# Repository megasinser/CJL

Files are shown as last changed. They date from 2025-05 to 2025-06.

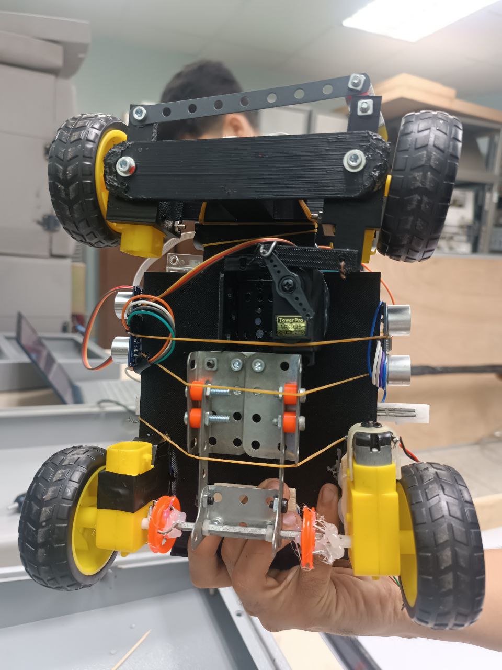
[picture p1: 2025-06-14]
v-photos/BOTTOM.jpg

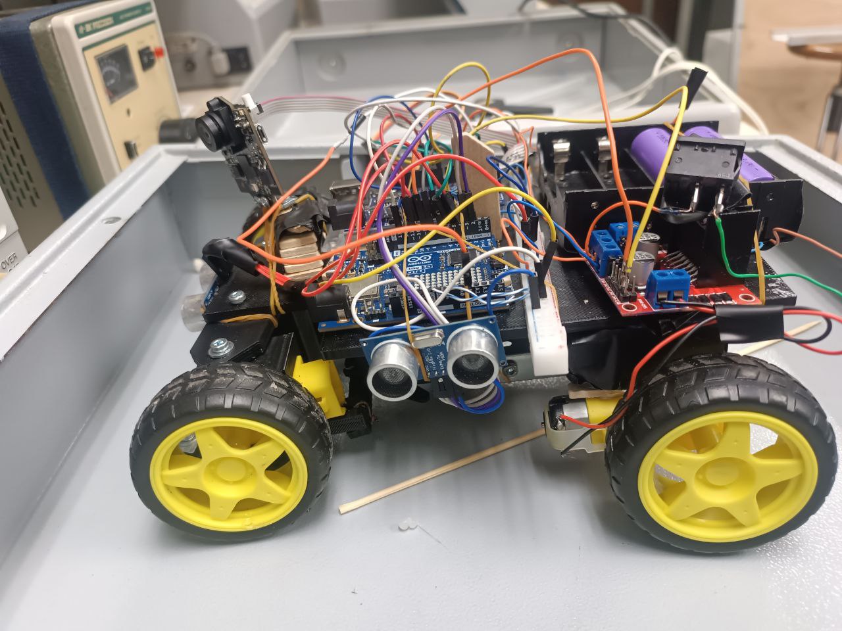
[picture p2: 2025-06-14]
v-photos/LEFT.jpg

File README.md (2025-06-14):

Hi, we are the CJL team, and this is our GitHub repository, where we will be explaining and providing all the relevant information regarding the development of our autonomous car for the WRO Future Engineers category.

Engineering materials
This repository contains engineering materials of a self-driven vehicle's model participating in the WRO Future Engineers competition in the season 2025.

Arduino UNO R3

Arduino UNO R4

Servomotor MG995

Ultrasonic sensor (3)

9v battery

Pixy CAM 2.1 with comunication cable

wheels (4)

Hobby Gearmotor - 140 RPM (2)

H bridge

mini proto board 

jumpers and UTP wires 

4 18650 battteries

## Content

* `t-photos` contains 2 photos of the team (an official one and one funny photo with all team members)

* `v-photos` contains 6 photos of the vehicle (from every side, from top and bottom)
* `video` contains the video.md file with the link to a video where driving demonstration exists
* `schemes` 

* In the picture you can watch how the components that make the car works are conected, without even considering the color detection system.

* `src` contains code of control software for all components which were programmed to participate in the competition

* `other`   

## Introduction and Project description

For the creation of our autonomous car, I utilized several key components: two Arduino boards, three ultrasonic sensors, an H-bridge, four 18650 batteries, a 3D printed chassis, a reduction motor, and three motor enclosures (one with a motor, two with reduction gears but without motors).

To start, I assembled the chassis, as shown in the photo, and proceeded to connect the two Arduino boards. The three ultrasonic sensors were strategically placed: one on the right side, one on the left, and one in the front. I defined the appropriate pins for each sensor to gather distance data, allowing the robot to detect obstacles and avoid collisions. This data was then used to implement the turning logic, helping the car navigate the track and avoid obstacles.

I also connected a reduction motor to another motor reduction housing via a gearbox, as required by the competition rules. The H-bridge was used to control the motor's direction, allowing it to move forward or backward depending on the signal received from the control system.

For color detection, I integrated the Pixy camera with an Arduino using the PixyMon software. The camera was programmed to detect red, green, orange, and blue colors. Red and green were used to identify blocks or obstacles on the track, while blue and orange  were designated for detecting the track's lines at each corner. The camera’s output was processed by an Arduino, and based on the detected color, the Arduino would send a signal to the second Arduino to control the car's movement. For instance, if the camera detected green, the car would turn left, and if green was detected, it would turn left.

Additionally, the Pixy camera sends information about the color detected (including the X and Y coordinates of the block) to the Arduino, which then sends a HIGH signal to specific pins. This signal is received by the second Arduino to trigger the appropriate response: turning left for red or right for green.

To track the car’s laps, I implemented a counter in the Arduino connected to the Pixy camera. Each time the camera detected a set of four orange lines, one at each corner of the track, it counted as a full lap. After three laps, the Arduino would send a stop signal to the motor Arduino to halt the motors.

The entire system was powered by a total of 8 volts from four 18650 batteries, with a 5-volt regulator used to supply power to the Arduino boards, sensors, and servos.

## About us

Meet Our Team:

We are a team made up of Luis, Carlos, and José, and we share a strong passion for robotics. Each one of us brings something unique to the table, and together, we work hard to create something truly amazing.

Carlos: Carlos is in charge of the mechanical and physical side of the vehicle. He’s the one who builds everything and makes sure the robot’s structure is solid and works well. His skills in mechanics are what make our robot functional and reliable.

José: José is the one who handles the programming and logic. He loves coding and is great at solving problems. His work ensures the robot works the way it’s supposed to and can make decisions on its own.

Luis: Luis is also focused on programming, but he’s especially good at connecting everything together and solving technical issues. His ability to troubleshoot and fix problems helps keep everything running smoothly.

Our Approach:

As a team, we’re all about working together and learning from each other. Carlos handles the physical build, José writes the code, and Luis makes sure everything fits together and works perfectly. We each have our strengths, and by combining them, we’re able to push the limits of what we can create in robotics. We’re excited to see where our skills and teamwork take us!

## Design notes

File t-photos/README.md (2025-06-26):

Team's photos
Team picture
funny picture

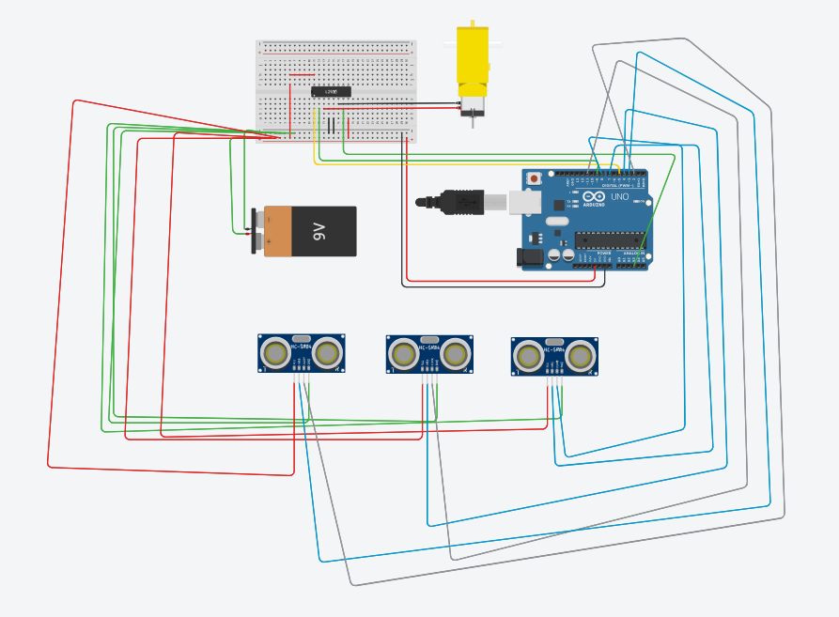
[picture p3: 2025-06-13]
schemes/image.png

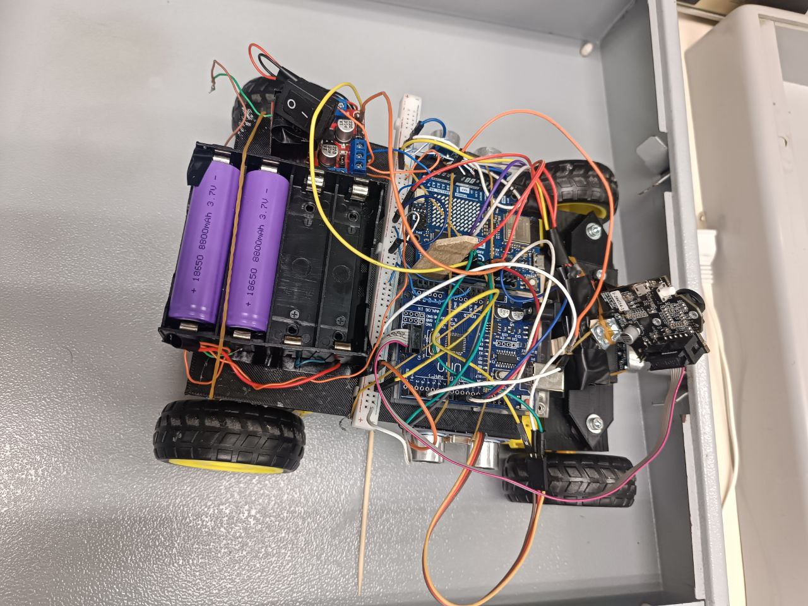
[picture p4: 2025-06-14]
v-photos/TOP.jpg

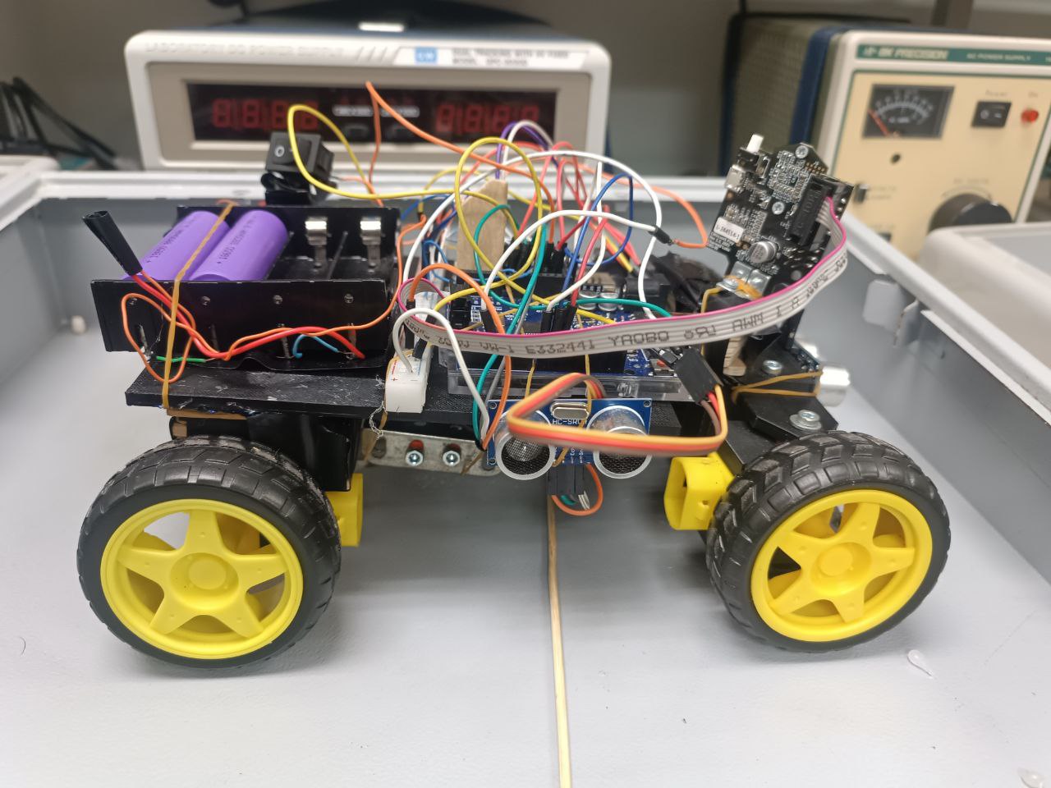
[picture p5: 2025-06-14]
v-photos/RIGHT.jpg

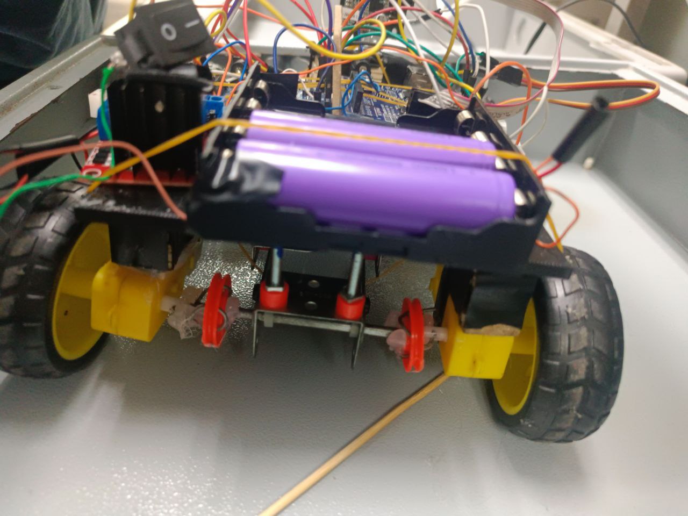
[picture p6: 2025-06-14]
v-photos/BACK.jpg

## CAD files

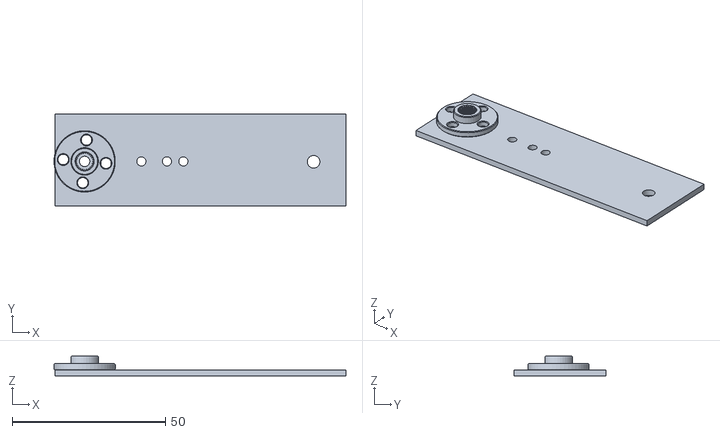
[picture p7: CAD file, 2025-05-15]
models/Direccion_parte_1.stl
95.3 x 30.0 x 6.50

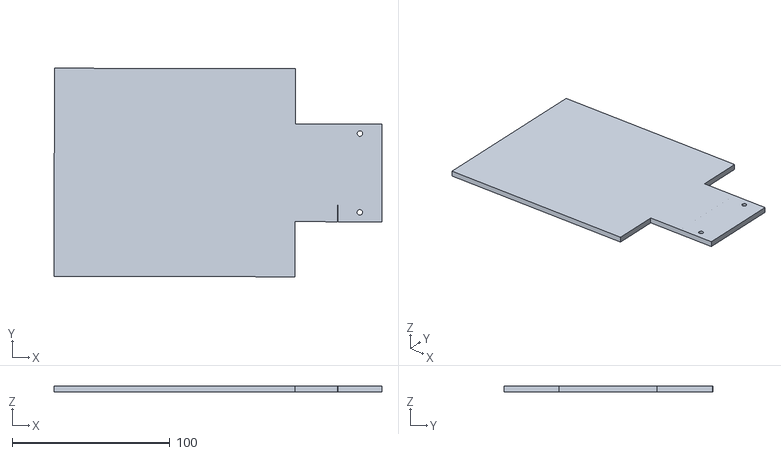
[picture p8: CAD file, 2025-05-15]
models/Chasis.stl
208.1 x 132.4 x 4.00

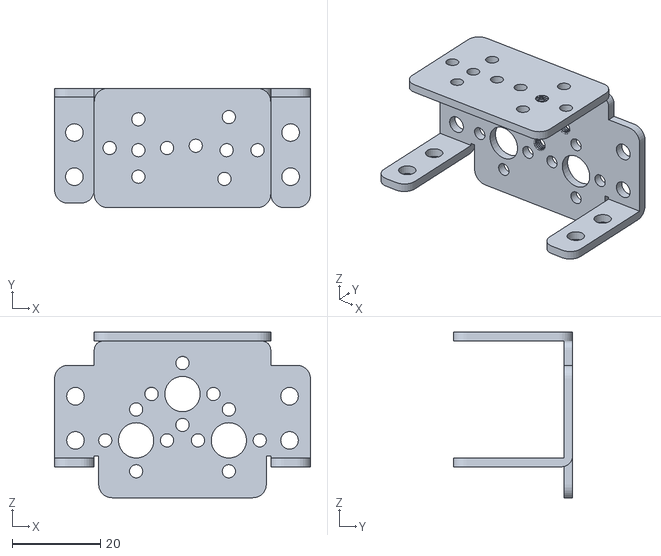
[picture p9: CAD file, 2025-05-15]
models/Soporte_Servo.stl
58.0 x 27.0 x 37.5

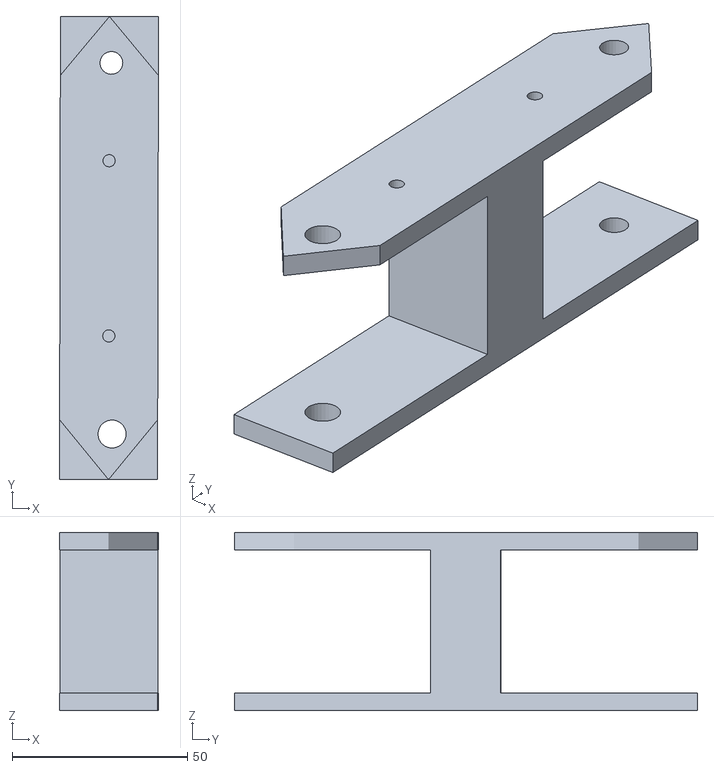
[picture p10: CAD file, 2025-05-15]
models/Soporte_Direccion.stl
28.3 x 132.2 x 50.8

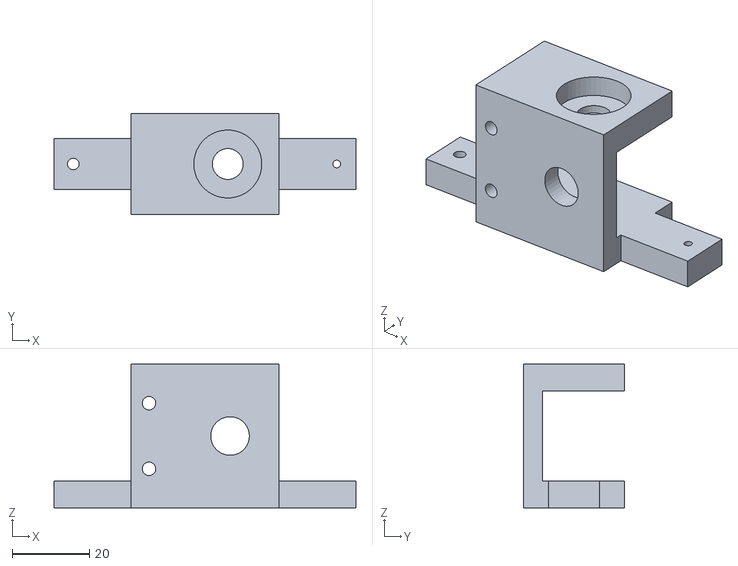
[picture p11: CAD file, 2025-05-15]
models/Abrazadera_A.stl
78.2 x 26.2 x 37.2

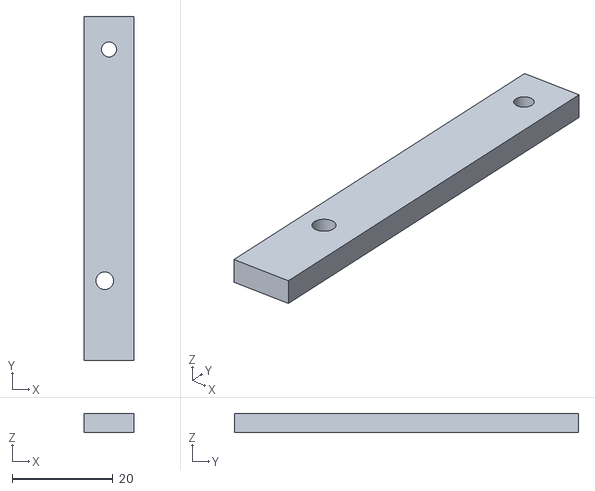
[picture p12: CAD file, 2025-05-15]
models/Direccion_parte_2.stl
10.0 x 68.4 x 3.80

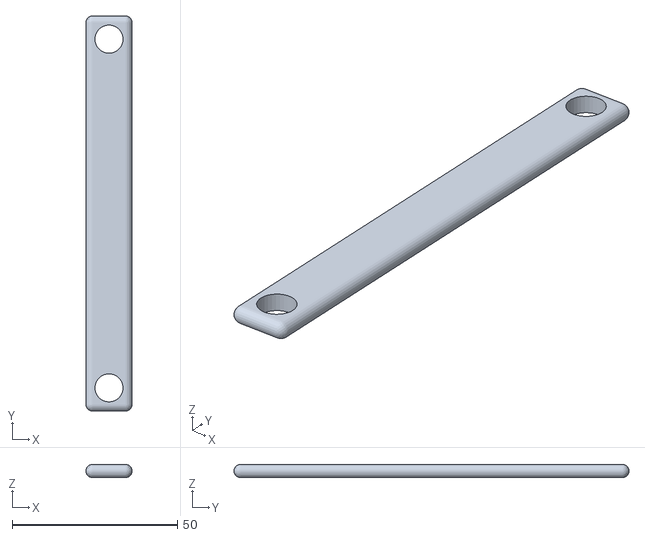
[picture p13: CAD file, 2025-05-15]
models/Barra_Direccion.stl
14.0 x 119.5 x 4.00

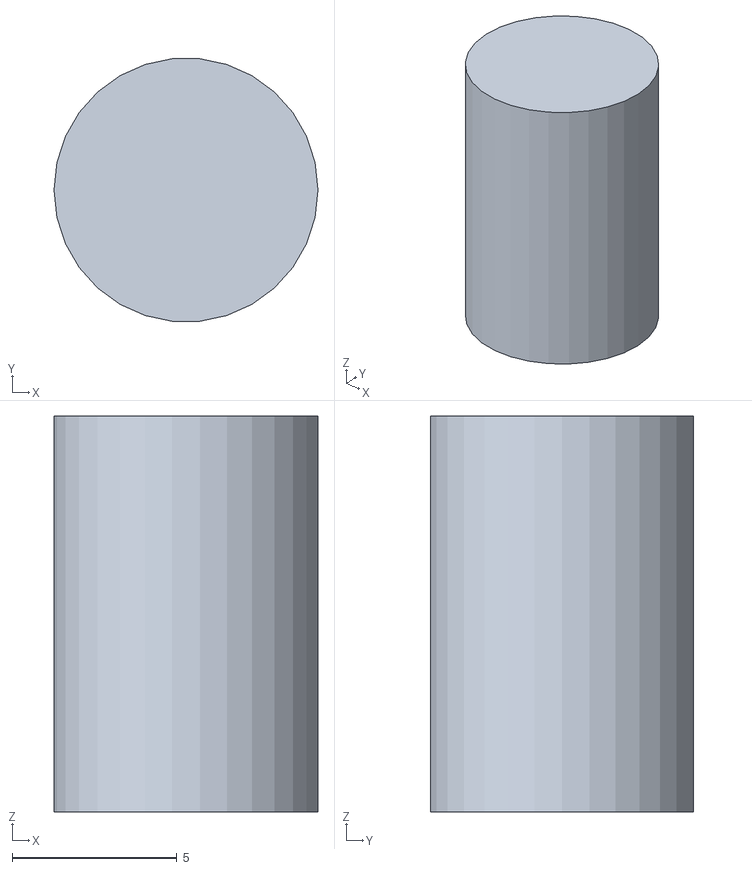
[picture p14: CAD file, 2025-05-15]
models/PosteABCD.stl
8.00 x 7.96 x 12.0

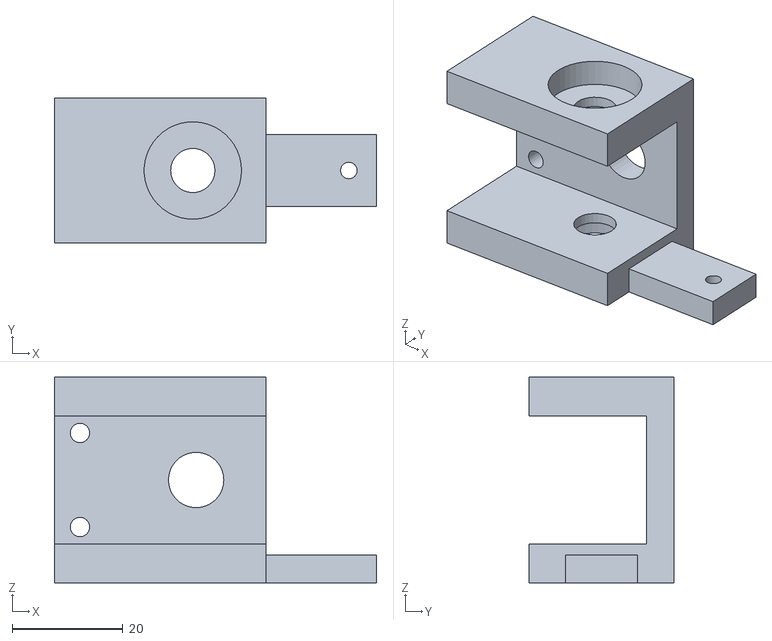
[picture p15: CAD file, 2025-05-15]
models/Abrazadera_B.stl
58.2 x 26.2 x 37.2

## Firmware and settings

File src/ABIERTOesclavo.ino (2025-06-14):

#include <Servo.h>
#include <NewPing.h>

// Definir pines
const int pinServo = 6;
const int pinMotorAdelante = 9;  // Pin PWM para el motor de avance
const int pinMotorAtras = A0;    // Pin PWM para el motor de retroceso (sin uso en este código)
const int pinEnable = 5;         // Pin para habilitar el puente H (Enable) para controlar la velocidad
const int pinAvviso = A1;        // Pin donde se recibe la señal de vuelta completada (A0)

// Definir ángulos del servo
const int ANGULO_CENTRO = 80;
const int ANGULO_IZQUIERDA = 160;
const int ANGULO_DERECHA = 20;
const int ANGULO_IZQUIERDA_C = 120;
const int ANGULO_DERECHA_C = 60;

// Configuración de los sensores ultrasónicos
const int PIN_TRIGGER_1 = 7;
const int PIN_ECHO_1 = 8;
const int MAX_DISTANCIA_1 = 150;  // Distancia máxima de detección en cm para el primer sensor (izquierda)
NewPing sonar1(PIN_TRIGGER_1, PIN_ECHO_1, MAX_DISTANCIA_1);

const int PIN_TRIGGER_2 = 3;
const int PIN_ECHO_2 = 2;
const int MAX_DISTANCIA_2 = 150;  // Distancia máxima de detección en cm para el segundo sensor (derecha)
NewPing sonar2(PIN_TRIGGER_2, PIN_ECHO_2, MAX_DISTANCIA_2);

const int PIN_TRIGGER_3 = 4;
const int PIN_ECHO_3 = 11;
const int MAX_DISTANCIA_3 = 200;  // Distancia máxima de detección en cm para el sensor de frente
NewPing sonar3(PIN_TRIGGER_3, PIN_ECHO_3, MAX_DISTANCIA_3);

// Rango de distancia de referencia (margen tolerable)
const int DISTANCIA_MIN = 20;  // Distancia mínima aceptable (en cm)
const int DISTANCIA_MAX = 30;  // Distancia máxima aceptable (en cm)

// Velocidad fija para los motores (controlada por el pin enable)
const int VELOCIDAD = 250;  // Ajusta la velocidad aquí (valor entre 0 y 255)

Servo miServo;  // Crear objeto servo

bool detenerRobot = false;  // Variable para determinar si detener el robot

void setup() {
  pinMode(13, INPUT);  // Pin 13 como entrada (rojo)
  pinMode(12, INPUT);  // Pin 12 como entrada (verde)
  pinMode(10, INPUT);  // Pin 10 como entrada (ninguno)
  pinMode(pinAvviso, INPUT);  // Configurar A0 (pinAvviso) como entrada
  
  // Inicializar el servo
  miServo.attach(pinServo);
  
  // Configuración de los pines de los motores
  pinMode(pinMotorAdelante, OUTPUT);
  pinMode(pinMotorAtras, OUTPUT);  // No se utiliza en este código
  pinMode(pinEnable, OUTPUT);  // Configurar el pin Enable como salida
  
  // Inicialización del servo en el centro
  miServo.write(ANGULO_CENTRO);

  // Configuración de la comunicación serial para monitorear la distancia
  Serial.begin(9600);
  Serial.println("Esclavo listo para recibir datos...");
}

void loop() {
  // Comprobar si se recibe la señal del primer Arduino para detener el robot
  int estadoAvviso = digitalRead(pinAvviso);  // Leer el pin A1
  
  if (estadoAvviso == HIGH) {
    Serial.println("Vueltas completadas. Deteniendo el robot...");
    detenerRobot = true;  // Cambiar el estado para detener el robot
  }

  if (detenerRobot) {
    // Si la variable detenerRobot es true, se detiene todo el funcionamiento del robot
    digitalWrite(pinMotorAdelante, LOW);  // Detener motor
    Serial.println("Robot detenido permanentemente.");
    return;  // Detener el ciclo del loop
  }

  int estadoRojo = digitalRead(13);  // Leer pin 13 (rojo)
  int estadoVerde = digitalRead(12);  // Leer pin 12 (verde)
  int estadoNinguno = digitalRead(10);  // Leer pin 10 (ninguno)

  // Imprimir el color detectado basado en el pin activo
  if (estadoRojo == HIGH) {
    Serial.println("Rojo detectado");
    miServo.write(ANGULO_DERECHA);  // Gira a la derecha
    delay(500);
  } 
  else if (estadoVerde == HIGH) {
    Serial.println("Verde detectado");
    miServo.write(ANGULO_IZQUIERDA);  // Gira a la izquierda
    delay(500);
  } 
  else if (estadoNinguno == HIGH) {
    Serial.println("No se detecta color");
    miServo.write(ANGULO_CENTRO);  // Mantener en el centro
  }

  delay(100);

  // Obtener las distancias medidas por los tres sensores ultrasónicos
  int distancia1 = sonar1.ping_cm();  // Primer sensor (izquierda)
  int distancia2 = sonar2.ping_cm();  // Segundo sensor (derecha)
  int distancia3 = sonar3.ping_cm();  // Tercer sensor (frente)
  
  // Imprimir las distancias medidas en el monitor serie
  Serial.print("Derecha: ");
  Serial.print(distancia1);
  Serial.print(" cm, ");
  Serial.print("Izquierda: ");
  Serial.print(distancia2);
  Serial.print(" cm, ");
  Serial.print("Frente: ");
  Serial.println(distancia3);
  
  // Comprobar las condiciones de los sensores
  if (distancia1 < 25 && distancia1 > 5) {
    // Gira completamente a la izquierda si alguna condición se cumple
    miServo.write(ANGULO_IZQUIERDA_C);
    Serial.println("Giro izquierda");
    delay(250);  // Mantener esta posición un breve tiempo
  } 
  else if (distancia2 == 0 && distancia3 < 70 && distancia3 > 1 || distancia2 > distancia1 && distancia3 < 70 && distancia3 > 1 ) {
    // Gira completamente a la derecha si alguna condición se cumple
    miServo.write(ANGULO_IZQUIERDA);
    Serial.println("Giro esquina izquierda");
    delay(1000);
    miServo.write(ANGULO_CENTRO);
    Serial.println("corrigiendo");
    delay(1000);
  }
  else if ( distancia2 < 25 && distancia2 > 5 ) {
    // Gira completamente a la derecha si alguna condición se cumple
    miServo.write(ANGULO_DERECHA_C);
    Serial.println("Giro derecha");
    delay(250);  // Mantener esta posición un breve tiempo
  }
  else if (distancia1 > distancia2 && distancia3 < 70 && distancia3 > 1 || distancia1 == 0 && distancia3 < 70 && distancia3 >1 ) {
    // Gira completamente a la derecha si alguna condición se cumple
    miServo.write(ANGULO_DERECHA);
    Serial.println("Giro esquina derecha");
    delay(1000);
    miServo.write(ANGULO_CENTRO);
    Serial.println("corrigiendo");
    delay(1000);
  }
      
  else {
    // Si ninguna condición se cumple, el servo se mantiene en el ángulo central
    miServo.write(ANGULO_CENTRO);
    Serial.println("Avanzando al frente");
    delay(150);
  }

  analogWrite(pinEnable, VELOCIDAD);  // Controlar la velocidad con el pin enable

  // Control de la dirección del motor
  digitalWrite(pinMotorAdelante, HIGH);  // Habilitar el motor para avanzar
  digitalWrite(pinMotorAtras, LOW);      // Desactivar el motor de retroceso
  
  // Agregar un pequeño retraso para estabilizar el robot (ajustable)
  delay(100);
}

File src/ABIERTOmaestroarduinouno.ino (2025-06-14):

#include <Pixy2.h>

// Definir pines de salida
const int pinRojo = 8;
const int pinVerde = 9;
const int pinNinguno = 10;
const int pinAvviso = 3;  // Pin para aviso de vueltas completadas

Pixy2 pixy;

int contadorEsquinas = 0;  // Contador de esquinas detectadas

// Variables para controlar el retraso entre detecciones
unsigned long tiempoUltimaDeteccion = 0;  // Para controlar el tiempo entre detecciones
const unsigned long retrasoDeteccion = 2000;  // 2 segundos de retraso entre detecciones

void setup() {
  pinMode(pinRojo, OUTPUT);   // Pin para rojo
  pinMode(pinVerde, OUTPUT);  // Pin para verde
  pinMode(pinNinguno, OUTPUT); // Pin para cuando no hay color
  pinMode(pinAvviso, OUTPUT); // Pin para indicar que se completaron las 12 vueltas

  Serial.begin(9600);  // Comunicación serial para depuración
  pixy.init();         // Inicializar Pixy2
}

void loop() {
  unsigned long tiempoActual = millis();  // Obtener el tiempo actual
  digitalWrite(pinAvviso, LOW);
  // Verificar si ha pasado el tiempo de retraso
  if (tiempoActual - tiempoUltimaDeteccion >= retrasoDeteccion) {
    // Obtener bloques detectados por Pixy
    pixy.ccc.getBlocks();

    // Verificar si se detectan bloques
    if (pixy.ccc.numBlocks) {
      for (int i = 0; i < pixy.ccc.numBlocks; i++) {
        byte colorData = pixy.ccc.blocks[i].m_signature;  // Firma del bloque detectado

        // Si se detecta un color y aún no se ha procesado este color, entramos en un ciclo while
        if (colorData == 3 || colorData == 4) {  // Detecta las esquinas (por ejemplo, firmas 3 y 4)
          // digitalWrite(pinRojo, HIGH);
           // Enciende pin 8 para rojo
           Serial.println("rojo");

          // digitalWrite(pinVerde, LOW);   // Apaga pin 9 para verde
          Serial.println("verde");

          digitalWrite(pinNinguno, LOW); // Apaga pin 10
          Serial.println("Esquina detectada");

          // Mantener el ciclo while mientras la firma 3 o 4 sea detectada
          while (pixy.ccc.numBlocks > 0) {
            pixy.ccc.getBlocks();  // Continuar obteniendo bloques detectados
            for (int j = 0; j < pixy.ccc.numBlocks; j++) {
              if (pixy.ccc.blocks[j].m_signature != colorData) {
                break;  // Si el color no es el mismo, salir del ciclo while
              }
            }
            delay(1000);  // Esperar un poco para evitar sobrecargar el procesador
          }

          // Al salir del ciclo while, significa que la esquina ya no está siendo detectada
          contadorEsquinas++;  // Incrementar el contador de esquinas
          Serial.print("Esquinas detectadas: ");
          Serial.println(contadorEsquinas);

          // Verificar si se han completado 12 esquinas
          if (contadorEsquinas >= 12) {
            Serial.println("Vueltas completadas");
            digitalWrite(pinAvviso, HIGH);  // Enviar HIGH al pin de aviso
            delay(100000);  // Mantener el HIGH por medio segundo
            //digitalWrite(pinAvviso, LOW);  // Volver a LOW el pin de aviso
            // contadorEsquinas = 0;  // Resetear el contador para comenzar de nuevo
          
          }

          // Resetear la detección de color después de un breve retraso
          tiempoUltimaDeteccion = tiempoActual;
          break;  // Salir del ciclo for principal después de procesar una esquina
        }
      }
    } else {
      digitalWrite(pinRojo, LOW);   // Apaga pin 8 para rojo
      digitalWrite(pinVerde, LOW);  // Apaga pin 9 para verde
      digitalWrite(pinNinguno, HIGH); // Enciende pin 10
      Serial.println("No se detectaron bloques");
    }
  }

  delay(100);  // Espera antes de la próxima lectura de Pixy
}
